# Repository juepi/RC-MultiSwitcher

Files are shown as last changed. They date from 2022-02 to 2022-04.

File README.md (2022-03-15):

# RC-MultiSwitcher
Hard- and software project to handle several RC (PWM) Servo In- and outputs as well as switched Outputs for LEDs and other loads.

## Purpose
My intention for this project was to be able to use a single RC channel for multiple purposes, like switching headlights, flashing lights, siren etc on my RC model. To be more flexible, the board provides 4 PWM servo inputs as well as 4 outputs, which can be used simultaneously. It additionally supports 6 N-channel MOSFET outputs, supporting an optional free-wheeling diode for inductive loads on every output.

## Requirements
Whilst the program has been tested and runs on an Nano 3.0 clone, you may want to use something stronger like a [Teensy 3.1+ board](https://www.pjrc.com/teensy/teensy31.html) for this. The Nano causes some jitter on the servo outputs, i assume due to the interrupts used to measure the PWM signal of the 2 servo input channels interfering with the servo library code.  
If you choose a different microcontroller, my recommendation is to make sure that it is 5V tolerant on the digital inputs (just to be sure). Also remenber that you'll require inputs that support interrupts for decoding the receivers PWM signals.

## Status
This is work in progress, the current code is a POC on decoding the 2 RC channels along with servo output. Still much work to do adding the functionality i want and also a PCB to hook things up to.  
Some documentation available in comments which should help you get things up and running.  
**Update 2022-02-08:** Implemented support for Teensy 3.1/3.2 boards, Servo output jitter is history now!  
**Update 2022-02-11:** Added KiCAD project with schematic and layout for Teensy 3.1+ based MCU. KiCAD project is finished so far, will add gerber data as soon as i've finished the first order at JLCPCB.  
**Update 2022-02-14:** KiCAD project finished after some minor layout improvements. Added gerber, drilling, placement files as well as BoM in "production" subfolder.  
**Update 2022-02-24:** Implemented minor changes on PCB (v1.1): added possibility to provide power via 2pin JST XH plug; added solder-pad to short-circuit fuse (use with caution!); updated manufacturing files  
**Updated 2022-03-04:** Ordered PCB just arrived (v1.0) and works perfectly well! Not yet tested: high power load and PWM output on MOSFET switches.  

## Usage
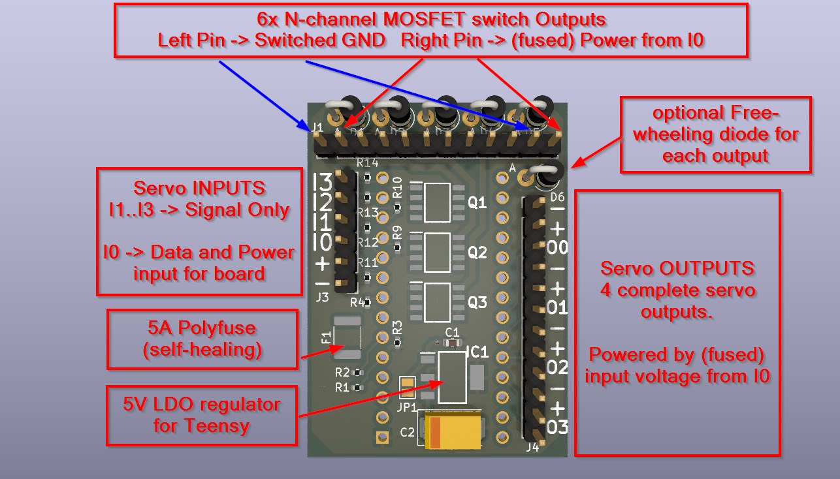
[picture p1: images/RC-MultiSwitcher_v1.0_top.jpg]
Bottom side of the PCB

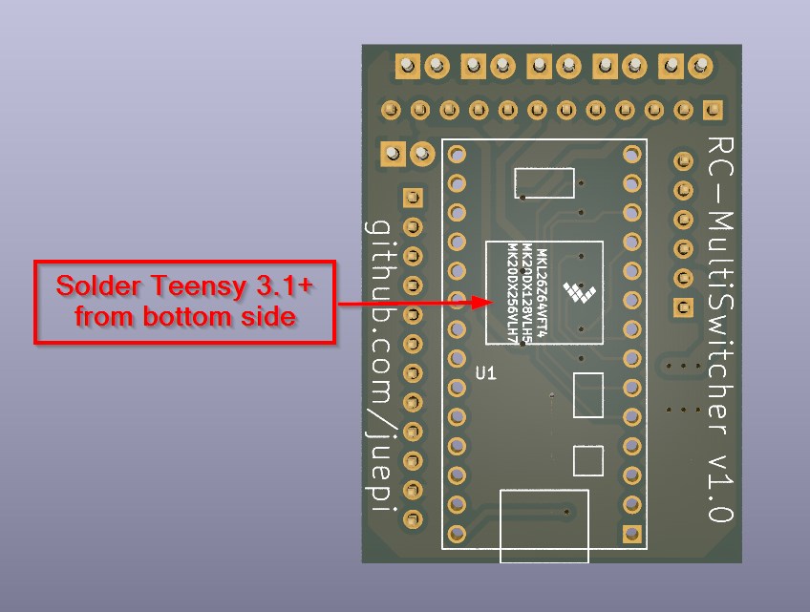
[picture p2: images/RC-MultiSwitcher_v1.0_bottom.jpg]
Servo Connector


have fun,  
Juergen

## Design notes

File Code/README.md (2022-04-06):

# RC-MultiSwitcher
PlatformIO based project to handle several RC (PWM) Servo In- and outputs as well as switched Outputs for LEDs and other loads.

## Purpose
My intention for this project was to be able to use a single RC channel for multiple purposes, like switching headlights, flashing lights, SIREN etc on my RC model. To be more flexible, 4 RC channels can be decoded (simultaneously), whilst 4 PWM output channels have been added along with some digital outputs. FlySky iBUS decoding has also been included to minimize cabling and get a max of 14 channels from your receiver.

## Requirements
Whilst the program (POC) has been tested and runs on an Nano 3.0 clone, you may want to use something stronger like a [Teensy 3.1+ board](https://www.pjrc.com/teensy/teensy31.html) for this. The Nano causes some jitter on the servo outputs, i assume due to the interrupts used to measure the PWM signal of the 2 servo input channels interfering with the servo library code.  
If you choose a different microcontroller, my recommendation is to make sure that it is 5V tolerant on the digital inputs (just to be sure). Also remember that you'll require inputs that support interrupts for decoding the receivers PWM signals.  
**Note:** When running on a Teensy 3.x, you can also use a serial bus interface (like iBus for FlySky) on Servo Input 0 to connect your receiver, as this will connect to the HW serial RX3 pin.

## Status
Some documentation available in comments which should help you get things up and running.  
**Update 2022-02-08:** Implemented support for Teensy 3.1/3.2 boards, Servo output signal jitter is history now!  
**Updated 2022-03-03:** Code is pretty finished now with v1.1.0. It compiles, but is not yet tested as my PCBs have not yet arrived.  
**Updated 2022-03-04:** PCB arrived, code tested and some bugs fixed. Code works now as expected.  
**Updated 2022-03-09:** Added testing mode for MOSFET outputs which can be enabled in `platformio.ini` (see `main.cpp`for details)  
**Updated 2022-03-14:** Added FlySky iBUS support. Connect SIN0 to RX iBUS "Servo" connector and you will be able to receive 14 channels at once. Note that enabling iBUS support completely disables the analog servo_decoder. As iBUS offers all channel states in PWM µs duty cycle, it can be used as in-place replacement for the servo_decoder.

## Changelog

### v1.2.2
- Change for personal usage; moved siren to CH3 (iBUS only); added foglights
- adopted pump PWM control

### v1.2.1
- Tweaked PWM MOSFET-output code
- Verified PWM mode for switch outputs - SW0 and SW1 run at 8.8kHz (`hardware-config.h`), all other at 50Hz (PWMServo)

### v1.2.0
- Added FlySky iBUS support (enable in `platformio.ini`, configure in `iBUS.h`)

### v1.1.2
- Added SW-output testing mode (can be anabled in `platformio.ini`)
- Fixed copy/paste error

### v1.1.1
- Fixed some copy/paste errors
- Adopted in/out-processing for new siren (does not require Servo output)
- Changed `analogWrite` handling of Switched outputs; PWMServo library sets PWM to 12bit resolution (system wide)
- optionally set PWM frequency for SW0 and SW1 (FTM1 timer) in `hardware-config.h`

### v1.1.0
- Implemented functions for processing outputs according to servo input positions (`in-out_processing.*`)
- Implemented switching MOSFET (PWM) outputs
- Added aliases (#defines) for In- and Outputs to make code easier to read (`hardware-config.h`)

### v1.0.2
- declared additional Servo in- and output pins to match hardware
- removed "low power" switched outputs -> only using MOSFET driven outputs

### v1.0.1
- Added Support for Teensy 3.1/3.2
- Added decoding function from Pulse-width to degrees (as an alternative to +/- 100%)
- Added Jitter-filter for servo inputs

have fun,  
Juergen

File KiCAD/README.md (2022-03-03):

# RC-MultiSwitcher
Hardware part of the project. Designed using KiCAD6, SMT parts used from the [JLCPCB parts list](https://jlcpcb.com/parts) to allow pre-assembling all the SMT parts.

## Purpose
Provide power to teensy MCU from BEC (up to 7.2V, Servo input 1) using LDO regulator provide hardware connections for Servo in- and outputs as wells as 6 N-channel MOSFET switched outputs (all 6 support PWM). The PCB has a 5A polyfuse installed at the power input to avoid overload (however, you will still have to make sure that you do not overload your BEC).

## Requirements
The [KiCAD Teensy libraries](https://github.com/XenGi/teensy_library) have been used for this board, they are included in the lib folder. The footprint has been slightly adopted to include only the main 2 pin-rows of the Teensy.

## Status
Schematic and layout finished, manufacturing data for [jlcpcb.com](https://jlcpcb.com/) added in "production" subfolder. 

## Changelog

### v1.1
- Added optional JST XH 2pin Power Input connector
- Added possibility to short circuit polyfuse with solder jumper on bottom side (use at your own risk!)
- updated manufacturing data
- Updated Net names of Switched Outputs to match code (SW0..SW5)

### v1.0
- Minor layout improvements
- changed C1 to different part with lower MOQ
- published manufacturing data

have fun,  
Juergen

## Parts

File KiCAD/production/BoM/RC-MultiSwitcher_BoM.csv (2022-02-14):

Comment | Designator | Footprint | LCSC part number
470nF/50V | C1 | Capacitor_SMD:C_0603_1608Metric | C77572
100µF/16V | C2 | Capacitor_Tantalum_SMD:CP_EIA-7343-31_Kemet-D | C171666
16V/5A | F1 | Fuse:Fuse_1812_4532Metric | C55996
LM2940IMP-5.0_NOPB | IC1 | Proj-Footprints:SOT230P700X180-4N | C13991
DMG9926USD-13 | Q1,Q2,Q3 | Proj-Footprints:SOIC127P600X175-8N | C154896
10k | R1,R2,R3,R4,R9,R10,R11,R12,R13,R14 | Resistor_SMD:R_0402_1005Metric | C25744

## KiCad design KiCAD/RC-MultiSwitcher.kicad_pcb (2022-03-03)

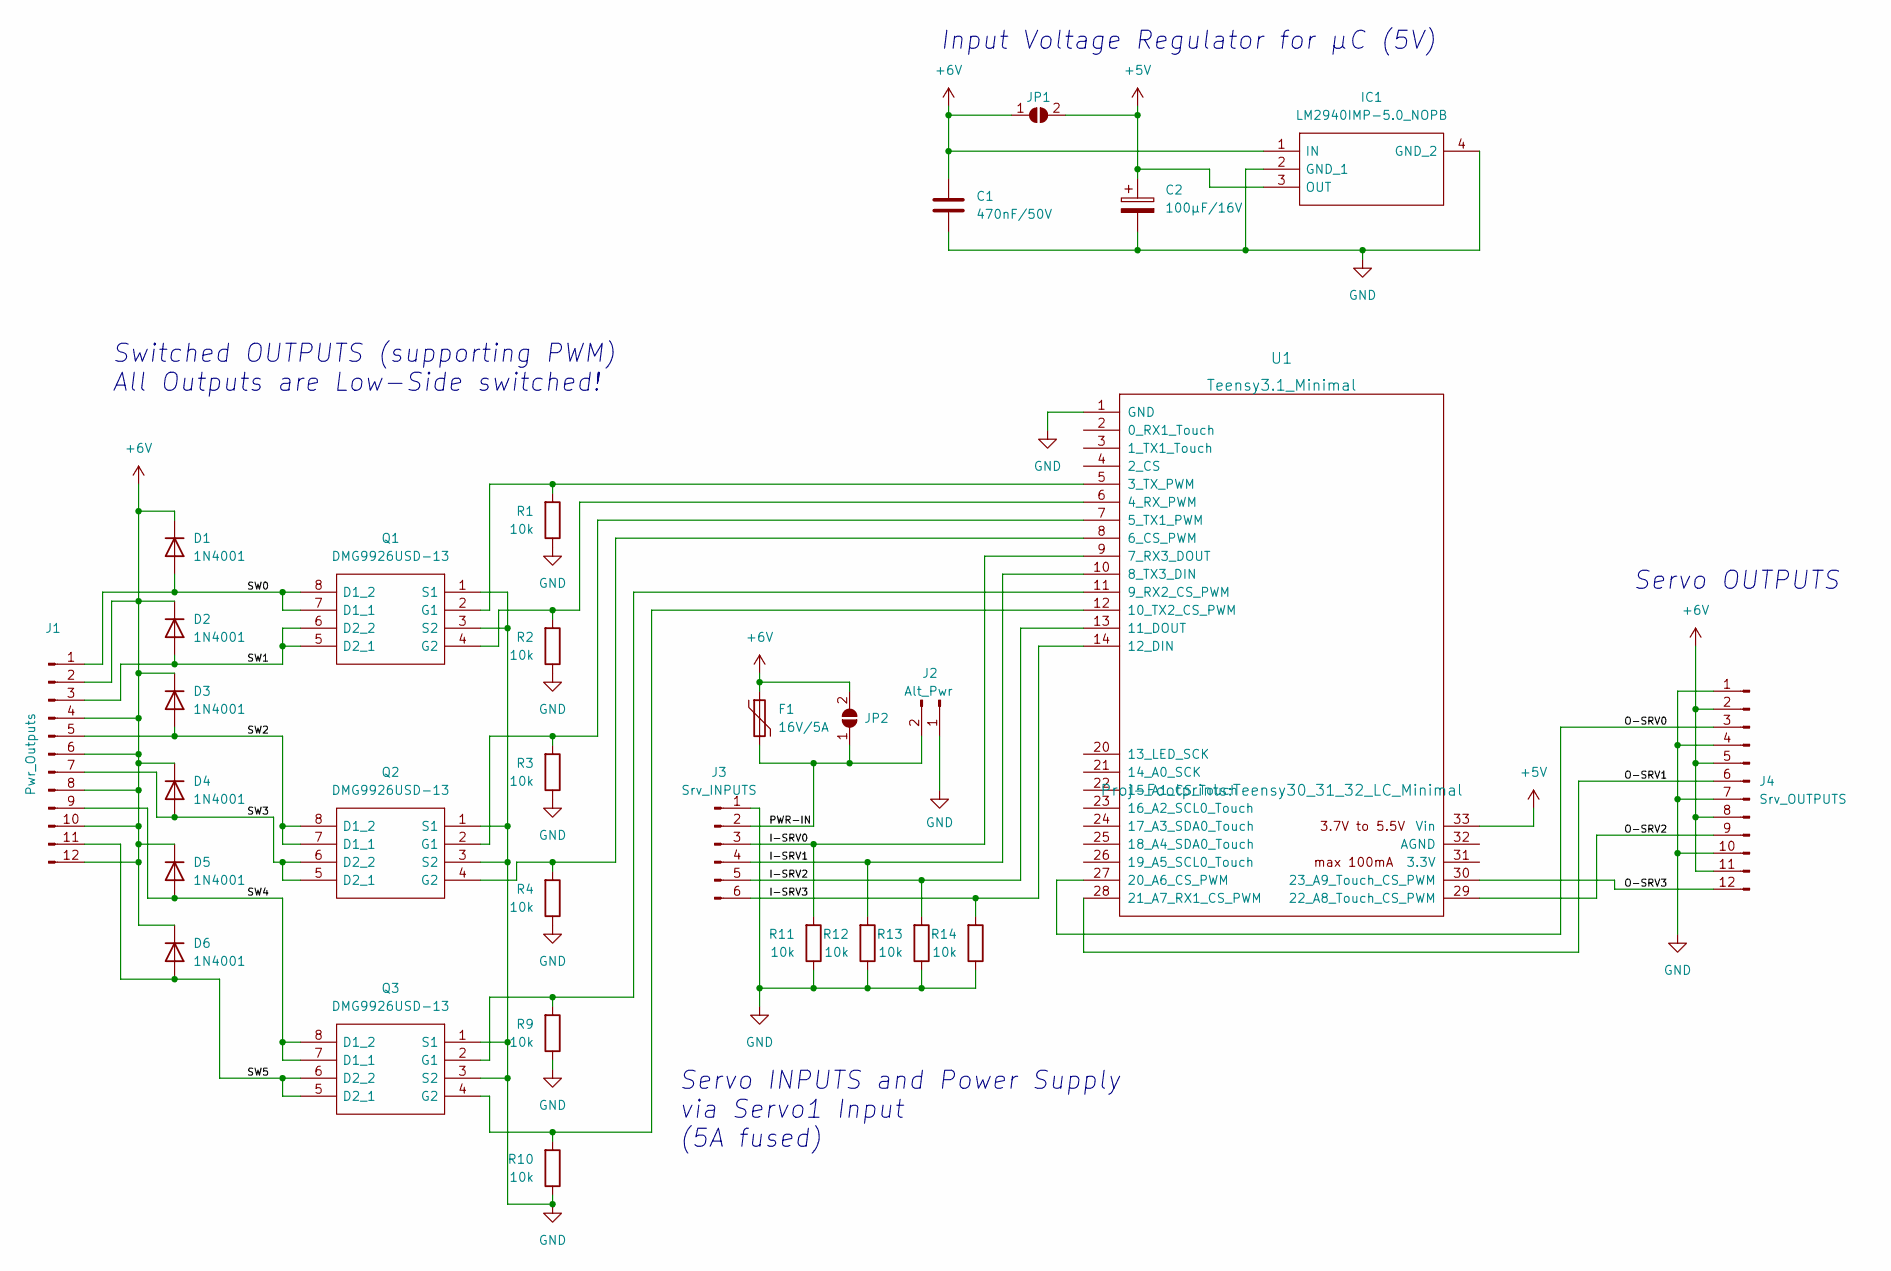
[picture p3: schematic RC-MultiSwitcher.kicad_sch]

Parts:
C1: 470nF/50V; C_0603_1608Metric; LCSC C77572
C2: 100µF/16V; CP_EIA-7343-31_Kemet-D; LCSC C171666
D1, D2, D3, D4, D5, D6: 1N4001; D_DO-41_SOD81_P2.54mm_Vertical_AnodeUp; LCSC DNP
F1: 16V/5A; Fuse_1812_4532Metric; LCSC C55996
IC1: LM2940IMP-5.0_NOPB; SOT230P700X180-4N; Manufacturer_Part_Number LM2940IMP-5.0/NOPB; LCSC C13991
J1: Pwr_Outputs; PinHeader_1x12_P2.54mm_Vertical; LCSC DNP
J2: Alt_Pwr; JST_XH_B2B-XH-A_1x02_P2.50mm_Vertical; LCSC DNP
J3: Srv_INPUTS; PinHeader_1x06_P2.54mm_Vertical; LCSC DNP
J4: Srv_OUTPUTS; PinHeader_1x12_P2.54mm_Vertical; LCSC DNP
JP1, JP2: SolderJumper-2_P1.3mm_Open_Pad1.0x1.5mm
Q1, Q2, Q3: DMG9926USD-13; SOIC127P600X175-8N; Manufacturer_Part_Number DMG9926USD-13; LCSC C154896
R1, R2, R3, R4, R9, R10, R11, R12, R13, R14: 10k; R_0402_1005Metric; LCSC C25744
U1: Teensy3.1_Minimal; Teensy30_31_32_LC_Minimal

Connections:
+5V: C2.1, IC1.3 (OUT), JP1.2 (B), U1.33 (Vin)
+6V: C1.1, D1.1 (K), D2.1 (K), D3.1 (K), D4.1 (K), D5.1 (K), D6.1 (K), F1.1, IC1.1 (IN), J1.2, J1.4, J1.6, J1.8, J1.10, J1.12, J4.2, J4.5, J4.8, J4.11, JP1.1 (A), JP2.2 (B)
/I-SRV0: J3.3, R11.2, U1.9 (7_RX3_DOUT)
/I-SRV1: J3.4, R12.2, U1.10 (8_TX3_DIN)
/I-SRV2: J3.5, R13.2, U1.13 (11_DOUT)
/I-SRV3: J3.6, R14.2, U1.14 (12_DIN)
/O-SRV0: J4.3, U1.27 (20_A6_CS_PWM)
/O-SRV1: J4.6, U1.28 (21_A7_RX1_CS_PWM)
/O-SRV2: J4.9, U1.29 (22_A8_Touch_CS_PWM)
/O-SRV3: J4.12, U1.30 (23_A9_Touch_CS_PWM)
/PWR-IN: F1.2, J2.2, J3.2, JP2.1 (A)
/SW0: D1.2 (A), J1.1, Q1.7 (D1_1), Q1.8 (D1_2)
/SW1: D2.2 (A), J1.3, Q1.5 (D2_1), Q1.6 (D2_2)
/SW2: D3.2 (A), J1.5, Q2.7 (D1_1), Q2.8 (D1_2)
/SW3: D4.2 (A), J1.7, Q2.5 (D2_1), Q2.6 (D2_2)
/SW4: D5.2 (A), J1.9, Q3.7 (D1_1), Q3.8 (D1_2)
/SW5: D6.2 (A), J1.11, Q3.5 (D2_1), Q3.6 (D2_2)
GND: C1.2, C2.2, IC1.2 (GND_1), IC1.4 (GND_2), J2.1, J3.1, J4.1, J4.4, J4.7, J4.10, Q1.1 (S1), Q1.3 (S2), Q2.1 (S1), Q2.3 (S2), Q3.1 (S1), Q3.3 (S2), R1.1, R2.1, R3.1, R4.1, R9.1, R10.1, R11.1, R12.1, R13.1, R14.1, U1.1 (GND)
unnamed: Q1.2 (G1), R1.2, U1.5 (3_TX_PWM)
unnamed: Q1.4 (G2), R2.2, U1.6 (4_RX_PWM)
unnamed: Q2.2 (G1), R3.2, U1.7 (5_TX1_PWM)
unnamed: Q2.4 (G2), R4.2, U1.8 (6_CS_PWM)
unnamed: Q3.2 (G1), R9.2, U1.11 (9_RX2_CS_PWM)
unnamed: Q3.4 (G2), R10.2, U1.12 (10_TX2_CS_PWM)

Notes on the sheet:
Servo INPUTS and Power Supply via Servo1 Input (5A fused)
Switched OUTPUTS (supporting PWM) All Outputs are Low-Side switched!
Input Voltage Regulator for µC (5V)
Servo OUTPUTS

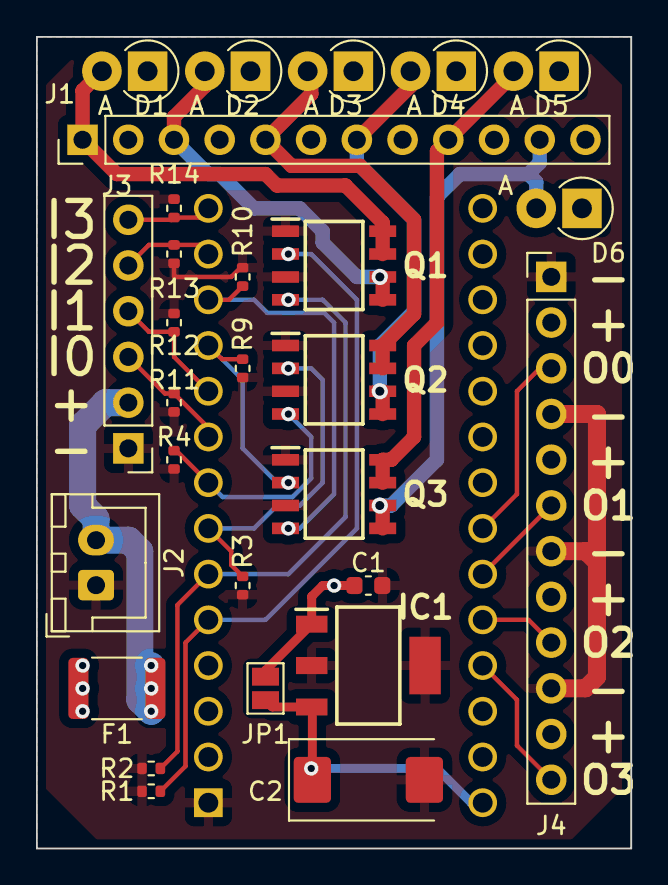
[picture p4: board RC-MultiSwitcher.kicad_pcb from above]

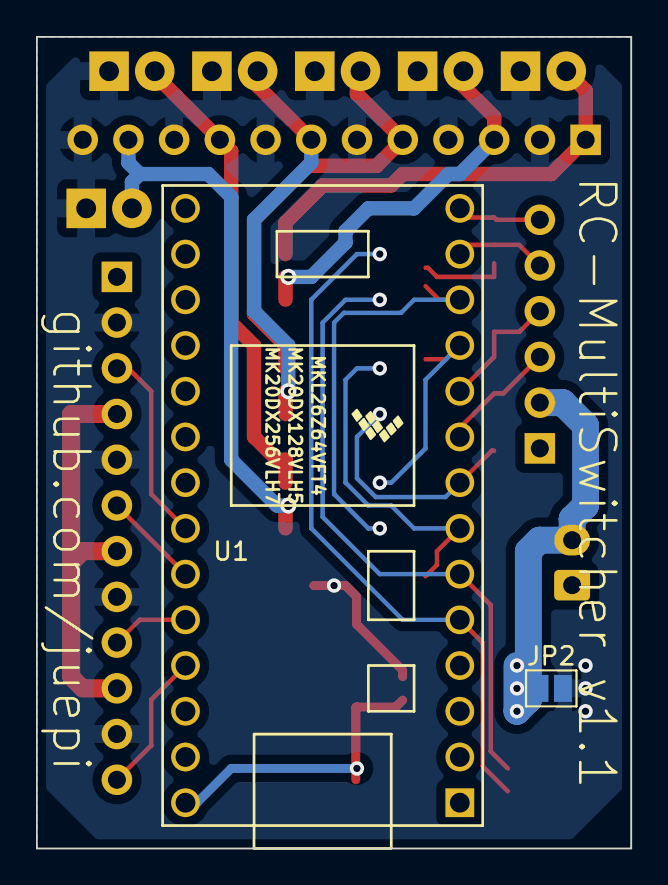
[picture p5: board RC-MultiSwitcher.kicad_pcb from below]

Board: 2 copper layers, 33.0 x 45.1 mm, 30 parts (2 on the bottom side), 24 nets.

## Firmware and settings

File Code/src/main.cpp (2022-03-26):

/*
 * RC-MultiSwitcher
 */

#include <Arduino.h>
#include "hardware-config.h"
#include "generic-config.h"
#include "common-functions.h"
#include "servo_decoder.h"
#include "in-out_processing.h"

// Helper Vars
unsigned long Out_last_refresh = 0;
#ifdef IBUS
bool iBUS_VALID = false;
#endif

/*
 * Setup
 * ========================================================================
 */
void setup()
{
  hw_setup();
  DEBUG_PRINTLN();
  DEBUG_PRINTLN(FIRMWARE_NAME);
  DEBUG_PRINTLN(FIRMWARE_VERSION);
#ifdef ONBOARD_LED
  // Signal setup finished
  ToggleLed(LED, 200, 6);
#endif
  DEBUG_PRINTLN("Setup finished.");
}

/*
 * Main Loop
 * ========================================================================
 */
void loop()
{
#ifdef IBUS
  if (millis() - iBus_last_decode > IBUS_TIMEOUT_MS)
  {
    iBUS_VALID = false;
  }
  else
  {
    iBUS_VALID = true;
  }
#else
  // Handle new signals from INPUT Servos (Interrupt routines in servo_decoder.cpp)
  if (b_SIN0_newPos)
  {
    // SIN0 alias RX_CH5
    SIN_POS[RX_CH5][POS] = Servo_PWM_to_Deg(SIN0_uS, SIN_POS[RX_CH5][POS]);
    SIN_POS[RX_CH5][STAT] = 1; // We've decoded to degrees
    // Process Input / Output mapping
    Process_RX_CH5();
    b_SIN0_newPos = false;
  }
  if (b_SIN1_newPos)
  {
    // SIN1 alias RX_CH6
    SIN_POS[RX_CH6][POS] = Servo_PWM_to_Pct(SIN1_uS, SIN_POS[RX_CH6][POS], DEFAULT_DEAD_ZONE);
    SIN_POS[RX_CH6][STAT] = 2; // We've decoded to percent
    // Process Input / Output mapping
    Process_RX_CH6();
    b_SIN1_newPos = false;
  }
#endif

#ifdef IBUS
  if (iBUS_VALID)
  {
    // IBus_readChan reports current state in µs, just as our servo decoder
    SIN_POS[RX_CH3][POS] = Servo_PWM_to_Deg(iBus_readChan(RX_CH3), SIN_POS[RX_CH3][POS]);
    SIN_POS[RX_CH3][STAT] = 1; // We've decoded to degrees
    // Process Input / Output mapping
    Process_RX_CH3();
    SIN_POS[RX_CH5][POS] = Servo_PWM_to_Deg(iBus_readChan(RX_CH5), SIN_POS[RX_CH5][POS]);
    SIN_POS[RX_CH5][STAT] = 1; // We've decoded to degrees
    // Process Input / Output mapping
    Process_RX_CH5();
    SIN_POS[RX_CH6][POS] = Servo_PWM_to_Pct(iBus_readChan(RX_CH6), SIN_POS[RX_CH6][POS], DEFAULT_DEAD_ZONE);
    SIN_POS[RX_CH6][STAT] = 2; // We've decoded to percent
    // Process Input / Output mapping
    Process_RX_CH6();
#ifdef ONBOARD_LED
    digitalWrite(LED, LEDOFF);
#endif
  }
  else
  {
    for (int i = 0; i <= 5; i++)
    {
      SIN_POS[i][STAT] = 0; // iBUS disconnected, channels invalid!
    }
#ifdef ONBOARD_LED
    digitalWrite(LED, LEDON);
#endif
  }
#else
  // Verify validity of servo INPUT signals (signals received within SRV_TIMEOUT)
  if (millis() > (SIN0_LAST_UPDATE + SRV_TIMEOUT))
  {
    SIN_POS[RX_CH5][STAT] = 0; // SIN0 invalid!
  }
  if (millis() > (SIN1_LAST_UPDATE + SRV_TIMEOUT))
  {
    SIN_POS[RX_CH6][STAT] = 0; // SIN1 invalid!
  }
#endif

  // Write stati to Servo and switched Outputs only once within OUTPUT_REFRESH
  if (millis() - Out_last_refresh >= OUTPUT_REFRESH)
  {
    Out_last_refresh += OUTPUT_REFRESH;
    // Set OUTPUT Servo Position
    ServOut0.write(SOUT_POS[WINCH]);

    // Set switched output states
    // Note: These are PWM Outputs with 12bit resolution! 0% (0) = Always Off; 100% (4096) = Always On
    // Anything between will result in PWM
    // ATTN: keep in mind that SW2-SW5 share the FTM0 timer with the Servo outputs --> fixed at 50Hz
    // SW0 and SW1 (FTM1 timer) frequency might be changed in hardware-config.h
    for (int i = 0; i <= 5; i++)
    {
#ifdef SW_TESTING
      // SW_TESTING Mode (enable in platformio.ini)
      // SIN3 is configured as INPUT_PULLUP, thus all SW* outputs are ENABLED by default unless SIN3 is pulled to GND
      if (digitalRead(SIN3))
      {
        // Enable all SW Outputs if SIN3 = HIGH
        Switches[i][SW_STATE] = 100;
      }
      else
      {
        // If SIN3 is pulled low (default), map RX_CH5 status to every SW Output (PWM Testing)
        if (SIN_POS[RX_CH5][STAT] == 1)
        {
          Switches[i][SW_STATE] = map(SIN_POS[RX_CH5][POS], 0, 180, 0, 100);
        }
      }
#endif
      // Set SW output states
      // make sure FETs are full OFF (0-2%), ON (98-100%) or PWM in between
      // This might be important when feeding Switches from a channel which does not reach full end positions -> tweak as required
      switch (Switches[i][SW_STATE])
      {
      case 0 ... 2:
        Switches[i][SW_STATE] = 0;
        break;
      case 3 ... 97:
        break;
      case 98 ... 100:
        Switches[i][SW_STATE] = 100;
        break;
      }
      // write to Output
      analogWrite(Switches[i][SW_PIN], map(Switches[i][SW_STATE], 0, 100, 0, 4096));
    }

    // Debug output (added here to avoid too much load on the serial port):
#ifdef IBUS
    if (!iBUS_VALID)
    {
      DEBUG_PRINTLN("iBUS disconnected!");
    }
#endif
    DEBUG_PRINT("CH5:\t" + String(SIN_POS[RX_CH5][POS]) + "\t\t CH6:\t" + String(SIN_POS[RX_CH6][POS]) + "\t\t SOUT0:\t" + String(SOUT_POS[0]));
    DEBUG_PRINTLN("\t   SW0: " + String(Switches[0][SW_STATE]) + "  SW1: " + String(Switches[1][SW_STATE]) + "  SW2: " + String(Switches[2][SW_STATE]) + "  SW3: " + String(Switches[3][SW_STATE]) + "  SW4: " + String(Switches[4][SW_STATE]) + "  SW5: " + String(Switches[5][SW_STATE]));
  }
}

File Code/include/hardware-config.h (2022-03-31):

/*
 *   Hardware / Board specific Settings
 */
#ifndef HARDWARE_CONFIG_H
#define HARDWARE_CONFIG_H

#include <Arduino.h>
#ifdef NANO_BOARD // board-specific Servo library selection
#include <Servo.h>
#else
#include <PWMServo.h>
#ifdef IBUS
#include "iBUS.h"
#endif
#endif // Servo library selection

// Declaration of Servo OUTPUT objects (board specific)
#ifdef NANO_BOARD
extern Servo ServOut0;
extern Servo ServOut1;
extern Servo ServOut2;
#else
extern PWMServo ServOut0;
extern PWMServo ServOut1;
extern PWMServo ServOut2;
#endif

// refresh time for Servo OUTPUTS ins ms
#define OUTPUT_REFRESH 40

// Define PINS to use for each in- and output
#ifdef NANO_BOARD
#define LED 13
// LED is active low
#define LEDON LOW
#define LEDOFF HIGH

// Servo INPUTS
#define SIN0 2
#define SIN1 3

// Servo OUTPUTS
#define SOUT0 9
#define SOUT1 10
#define SOUT2 11

// Switched Outputs (for LEDs etc.)
#define SW0 14
#define SW1 15
#define SW2 16
#define SW3 17
#define SW4 18
#define SW5 19
#endif // NANO_BOARD

#ifdef T31_BOARD
#define LED 13
#define LEDON HIGH
#define LEDOFF LOW

// Servo INPUTS
#define SIN0 7
#define SIN1 8
#define SIN2 11
#define SIN3 12

// Servo OUTPUTS
// These Pins use Timer FTM0 set to 50Hz @ 12bit resolution by PWMServo library! Do not change!
#define SOUT0 20
#define SOUT1 21
#define SOUT2 22
#define SOUT3 23

// Switched Outputs (N-channel MOSFETs sum current 5A -> polyfuse -> watch out for your BEC!)
// All of these pins support PWM! Resolution is 12bit for all PWM pins (->PWMServo)
#define SW0 3  // FTM1 Timer
#define SW1 4  // FTM1 Timer
#define SW2 5  // FTM0 Timer!
#define SW3 6  // FTM0 Timer!
#define SW4 9  // FTM0 Timer!
#define SW5 10 // FTM0 Timer!

// PWM Frequency for Switched Outputs SW0 and SW1 (optional, defaults to 488Hz for Teensy 3.1)
// NOTE: Only change for FTM1! Resolution is 12bit for all PWM pins (->PWMServo)
// see documentation: https://www.pjrc.com/teensy/td_pulse.html
#define FTM1_FREQ 8789.062
#define FTM1_PIN SW0
#endif // T31_BOARD

// 2D Array for switched Outputs
// First Row: PIN of switch Element 0 = SW0, Element 1 =SW1 ...
// Second Row: OUTPUT-State of switch (0..100% -> PWM!)
extern int Switches[6][2];

// Create some human readable Switch Aliases
#define PUMP 0
#define HEADLIGHTS 1
#define BLUELAMP 2
#define SIREN 3
#define FOGLIGHTS 4
#define SW_PIN 0
#define SW_STATE 1

// Array for desired Servo OUTPUT Positions (0..180°)
// Usage: Element 0 = SOUT0, Element 1 = SOUT1 ...
// we currently use 1 out of 4 servo outputs
extern short SOUT_POS[1];

// Create some human readable Servo Output Aliases
#define WINCH 0

// 2D Array for measured Servo INPUT Positions (0..180° or -100%..100%)
// First row: measured servo position; second row: servo signal status (0=SignalInvalid;1=Degrees;2=Percent)? -> SignalInvalid is set if input is not updated within SRV_TIMEOUT
// Usage: Element 0 = SIN0, Element 1 = SIN1 ...
// we currently use 2 out of 4 servo inputs
extern short SIN_POS[6][2];

// Create some human readable Servo Input Aliases
#define RX_CH1 0
#define RX_CH2 1
#define RX_CH3 2
#define RX_CH4 3
#define RX_CH5 4
#define RX_CH6 5
#define POS 0
#define STAT 1
#define STAT_ERR 0
#define STAT_DEG 1
#define STAT_PCT 2

// Pump motor requires minimum PWM duty cycle to start running. Also define max
#define PUMP_MIN_PWM 60
#define PUMP_MAX_PWM 100

// Hardware setup function
extern void hw_setup();

#endif // HARDWARE_CONFIG_H

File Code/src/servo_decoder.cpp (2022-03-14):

/*
 * Servo decoder Functions
 */

#include <Arduino.h>
#include "hardware-config.h"
#include "servo_decoder.h"

#ifndef IBUS
// Variable definitions
volatile unsigned short SIN0_uS = 0;         // length of PWM signal in µS
volatile unsigned long SIN0_LAST_UPDATE = 0; // millis() of last servo PWM decode
volatile unsigned long SIN0_RE_micros = 0;   // micros() of rising edge (for length measurement in ISR)
volatile unsigned short SIN1_uS = 0;
volatile unsigned long SIN1_LAST_UPDATE = 0;
volatile unsigned long SIN1_RE_micros = 0;

volatile boolean b_SIN0_newPos = false; // new position detected?
volatile boolean b_SIN1_newPos = false;

void ISR_SIN0()
{
    // Rising edge
    if (digitalRead(SIN0) == HIGH)
    {
        // save the current micros
        SIN0_RE_micros = micros();
    }
    else
    {
        // Falling edge, calculate PWM length
        if (SIN0_RE_micros && (b_SIN0_newPos == false))
        {
            SIN0_uS = (unsigned short)(micros() - SIN0_RE_micros);
            SIN0_RE_micros = 0;
            // Signal new position available
            b_SIN0_newPos = true;
            SIN0_LAST_UPDATE = millis();
        }
    }
}

void ISR_SIN1()
{
    // Rising edge
    if (digitalRead(SIN1) == HIGH)
    {
        // save the current micros
        SIN1_RE_micros = micros();
    }
    else
    {
        // Falling edge, calculate PWM length
        if (SIN1_RE_micros && (b_SIN1_newPos == false))
        {
            SIN1_uS = (unsigned short)(micros() - SIN1_RE_micros);
            SIN1_RE_micros = 0;
            // Signal new position available
            b_SIN1_newPos = true;
            SIN1_LAST_UPDATE = millis();
        }
    }
}
#endif // !IBUS

short Servo_PWM_to_Pct(unsigned int PWMlength, short OldPctVal, byte DeadZone)
{
    short Percent_Pos = 0;
    unsigned short Neutral = SRV_CENTER; //just to avoid compiler warning
    if (PWMlength >= (Neutral + DeadZone))
    {
        Percent_Pos = map(PWMlength, SRV_CENTER, SRV_MAX, 0, 100); // 0% - 100%
    }
    else if (PWMlength <= (Neutral - DeadZone))
    {
        Percent_Pos = map(PWMlength, SRV_MIN, SRV_CENTER, -100, 0); // -100% - 0%
    }
    else
    {
        Percent_Pos = 0; //Servo Neutral within dead zone
    }
    if (abs(Percent_Pos - OldPctVal) >= JITTER)
    {
        return Percent_Pos;
    }
    // Jitter detected, return old value
    return OldPctVal;
}

short Servo_PWM_to_Deg(unsigned int PWMlength, short OldDegVal)
{
    short Deg_Pos = 0;
    unsigned short Neutral = SRV_CENTER; //just to avoid compiler warning
    if (PWMlength > Neutral)
    {
        Deg_Pos = map(PWMlength, SRV_CENTER, SRV_MAX, 91, 180); // 91 - 180°
    }
    else if (PWMlength < Neutral)
    {
        Deg_Pos = map(PWMlength, SRV_MIN, SRV_CENTER, 0, 89); // 0 - 89°
    }
    else
    {
        Deg_Pos = 90; //Servo Neutral 90°
    }
    if (abs(Deg_Pos - OldDegVal) >= JITTER)
    {
        return Deg_Pos;
    }
    // Jitter detected, return old value
    return OldDegVal;
}

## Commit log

2022-02-08 added teensy support; v1.0.1
2022-02-11 added KiCAD schematic and layout; minor code updates
    [RC-MultiSwitcher.kicad_pcb, RC-MultiSwitcher.kicad_sch]
2022-02-14 minor layout improvements; added manufacturing data
    [RC-MultiSwitcher-B_Cu.gbl, RC-MultiSwitcher-B_Mask.gbs, RC-MultiSwitcher-B_Paste.gbp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]
2022-02-14 added pcb usage infos
2022-02-24 minor update to PCB
    [RC-MultiSwitcher-B_Cu.gbl, RC-MultiSwitcher-B_Mask.gbs, RC-MultiSwitcher-B_Paste.gbp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]
2022-03-03 major code updates
    [RC-MultiSwitcher.kicad_pcb, RC-MultiSwitcher.kicad_sch]
2022-03-03 added option to set PWM frequency for SW outputs
2022-03-04 code updated after testing with PCB HW v1.0
2022-03-07 changed SW pinout to be able to use high frequency PWM for pump motor
2022-03-15 testing PWM Switches - buggy
    [main.cpp]
2022-03-15 minor code tweaking for PWM switch outputs
2022-03-26 adopted in-out-handling for personal use case
